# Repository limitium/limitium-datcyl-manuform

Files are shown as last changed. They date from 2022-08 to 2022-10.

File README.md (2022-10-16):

# Limitium' dactyl manuform
Default is great, however I didn't find a way to use it without hand rests. 

This build solves the problem of missing hand rests.

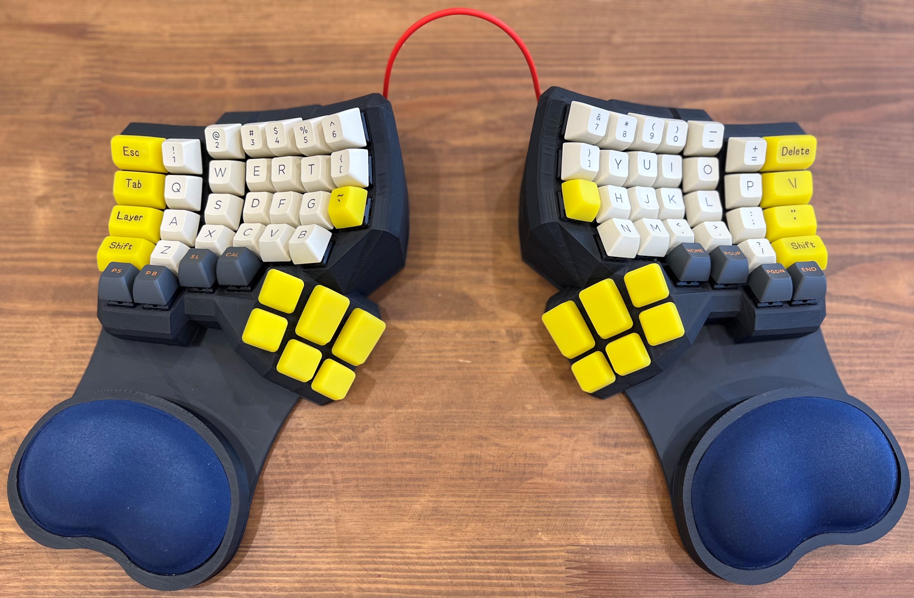
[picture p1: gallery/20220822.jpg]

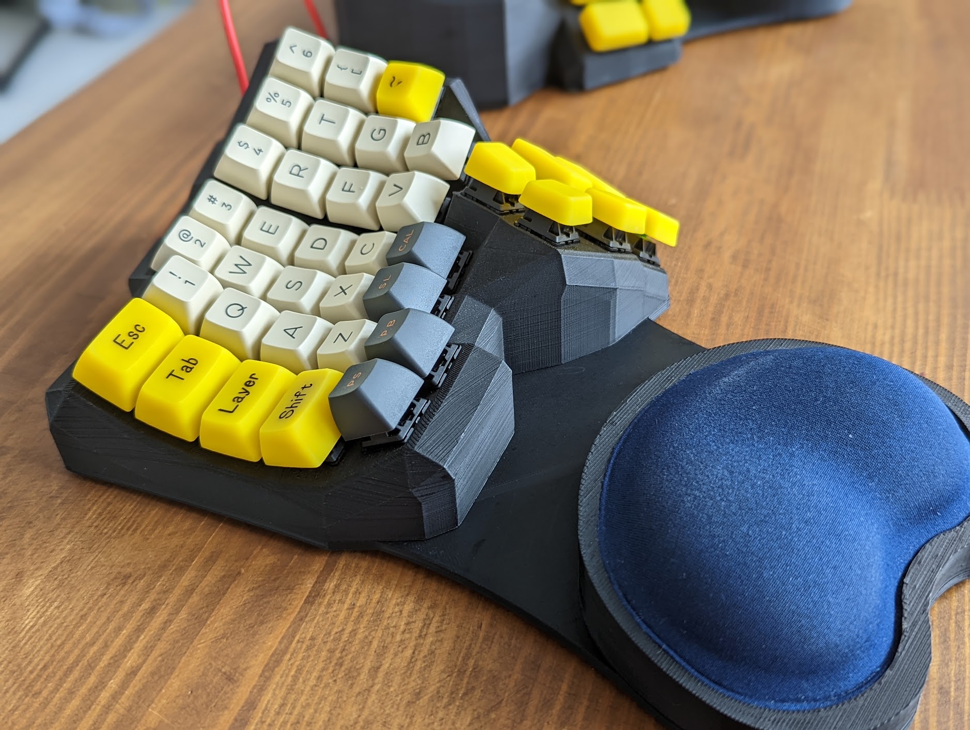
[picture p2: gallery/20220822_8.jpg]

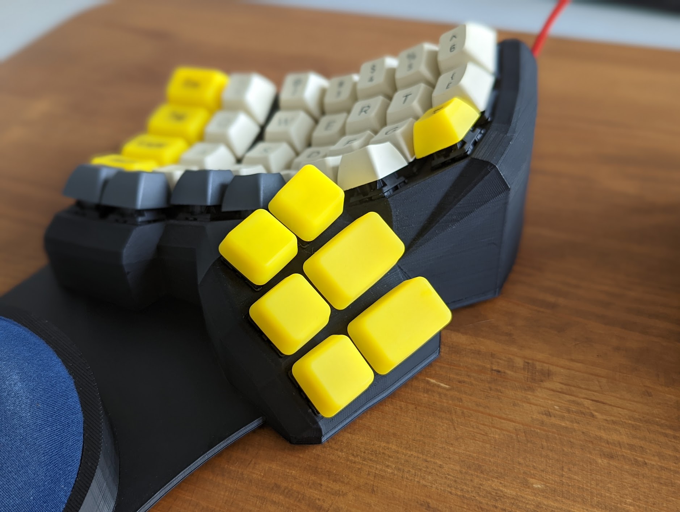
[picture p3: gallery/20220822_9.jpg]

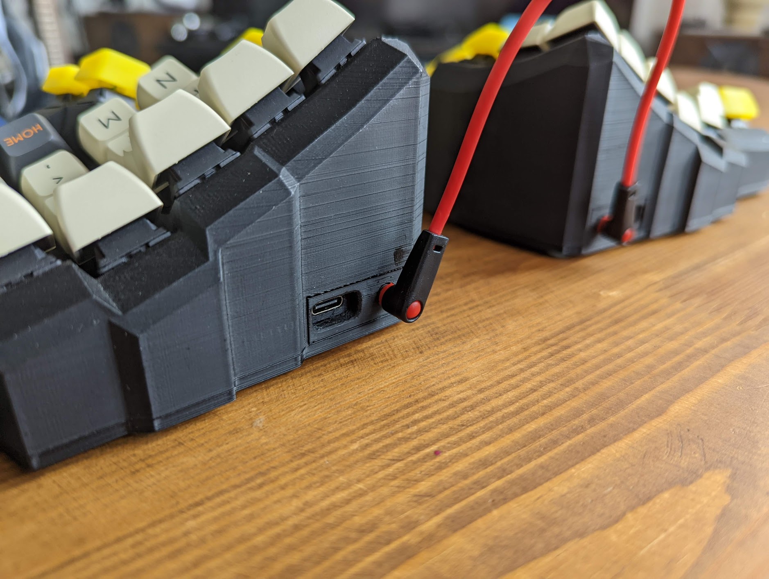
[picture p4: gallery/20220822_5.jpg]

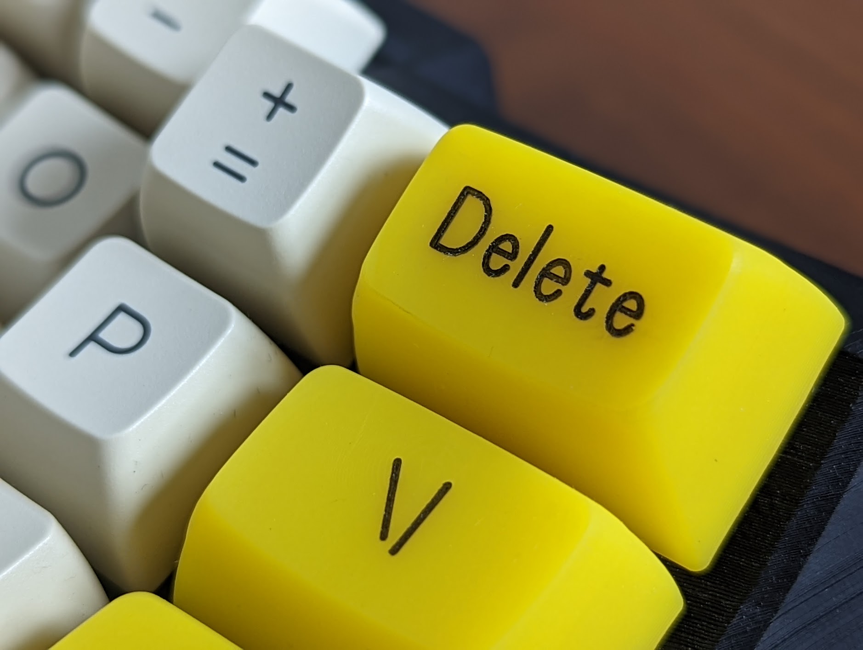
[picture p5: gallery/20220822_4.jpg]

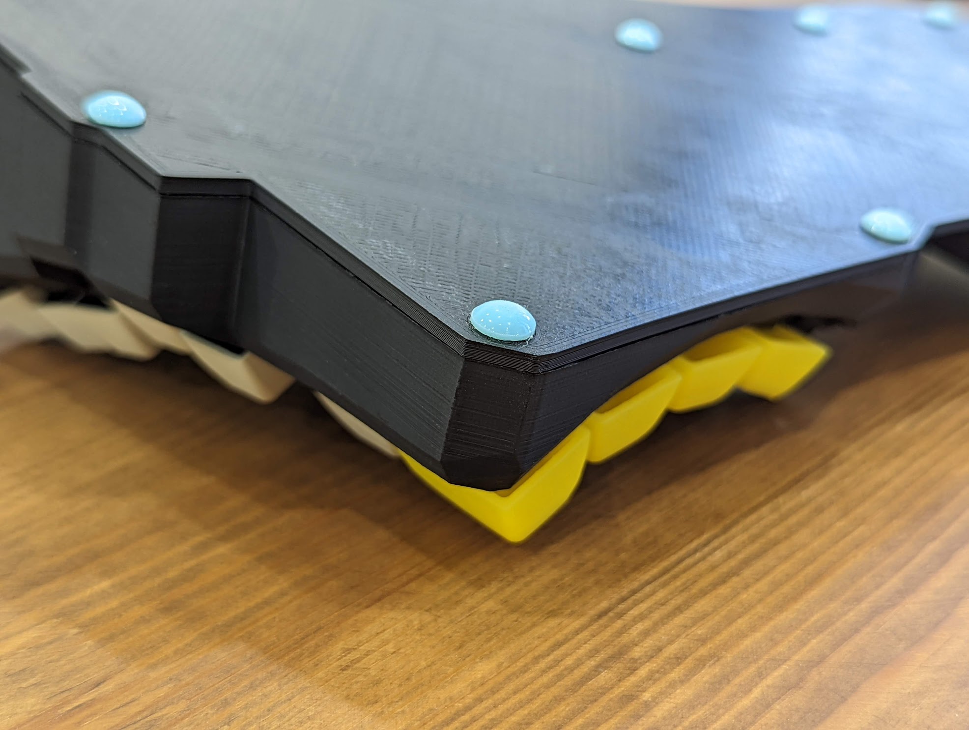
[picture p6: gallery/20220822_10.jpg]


## Table of contents
- [Limitium' dactyl manuform](#limitium-dactyl-manuform)
  - [Table of contents](#table-of-contents)
- [Build](#build)
  - [BOM](#bom)
  - [Body](#body)
    - [Handrest](#handrest)
    - [Promicro holder](#promicro-holder)
  - [Keycaps](#keycaps)
    - [ASA profile](#asa-profile)
      - [Carbon Retro Keycap Set from Akko](#carbon-retro-keycap-set-from-akko)
      - [Custom KeyV2](#custom-keyv2)
  - [Wiring](#wiring)
  - [Firmware](#firmware)

# Build

## BOM
* ANYCUBIC 4Max Pro 2.0 FDM 3D Printer        https://www.aliexpress.com/item/3256801441789044.html 186$
* ANYCUBIC Mono 4k UV Resin Printer           https://www.aliexpress.com/item/3256802616795467.html 181$
* AKKO Carbon Retro keycaps AKKO Carbon Retro https://www.aliexpress.com/item/3256803365319134.html 66$
* 74 cherry mx like switches                  https://www.aliexpress.com/item/3256801888735506.html 48$
* 74 1N4148 diods                             https://www.aliexpress.com/item/2251832635934304.html 1$
* 0.3 Brass copper wire                       https://www.aliexpress.com/item/2251832673616354.html 1.4$
* 2 usb-c promicro controller                 https://www.aliexpress.com/item/3256801435571628.html 15$
* 20 M3 3mm length self tapping insert        https://www.aliexpress.com/item/2251832821826942.html 1.5$
* 20 M3 flat hex screws                       https://www.aliexpress.com/item/2255799867108667.html 2$
* 20 silicone pads                            https://www.aliexpress.com/item/3256802432366448.html 3$
* 2 XH2.54 6p 90degree connector              https://www.aliexpress.com/item/2251832636946873.html 2$
* 2 XH2.54 7p 90degree connector              https://www.aliexpress.com/item/2251832636946873.html 2$
* 2 XH2.54 6p single head cable               https://www.aliexpress.com/item/3256801288158320.html 2$
* 2 XH2.54 7p single head cable               https://www.aliexpress.com/item/3256801288158320.html 2$
* 2 TRRS sockets                              https://www.aliexpress.com/item/2251832834540787.html 1.4$
* TRRS cable                                  https://www.aliexpress.com/item/3256801400545299.html 2.4$
* 2 heart-shaped wrist rest                   https://www.aliexpress.com/item/3256801631342023.html 11$
* eSun 0.5 yellow washable resin              https://www.aliexpress.com/item/3256802101772974.html 19$
* Sunlu black abs                             https://www.aliexpress.com/item/2255801034999072.html 18$

## Body
Different body types and modifications were tried, but ended up with a carbonfet fork of Dactyl manuform with a little thumb cluster tweaking https://github.com/limitium/dactyl-manuform

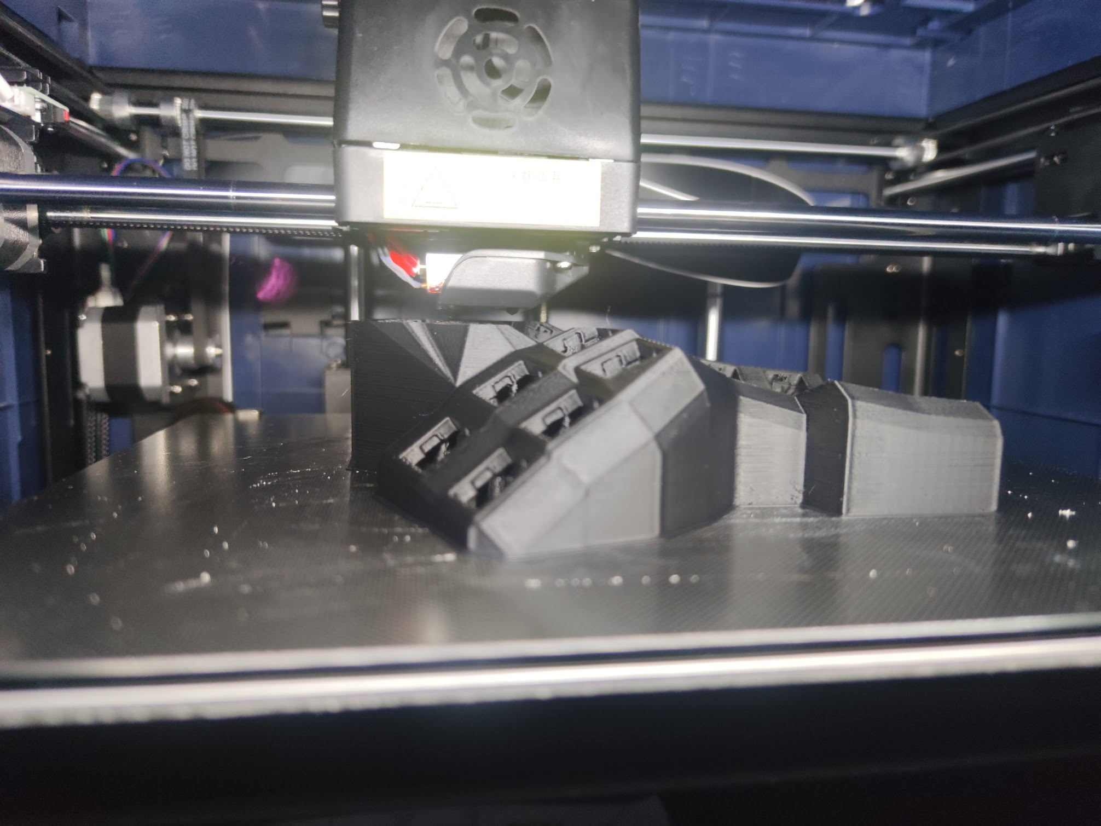
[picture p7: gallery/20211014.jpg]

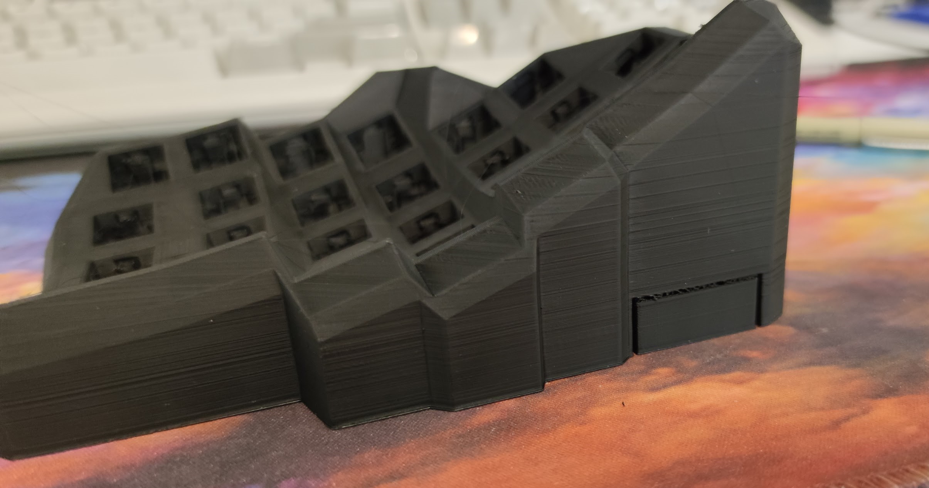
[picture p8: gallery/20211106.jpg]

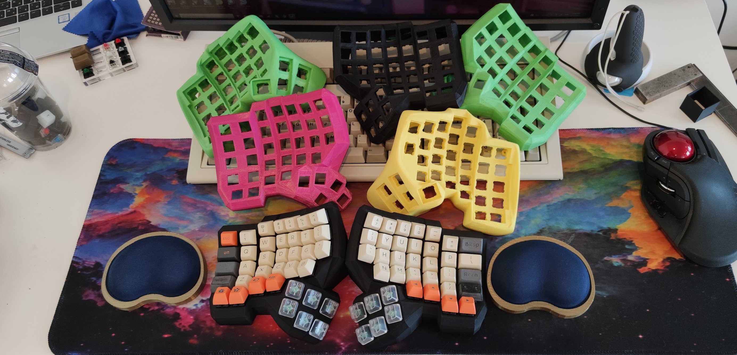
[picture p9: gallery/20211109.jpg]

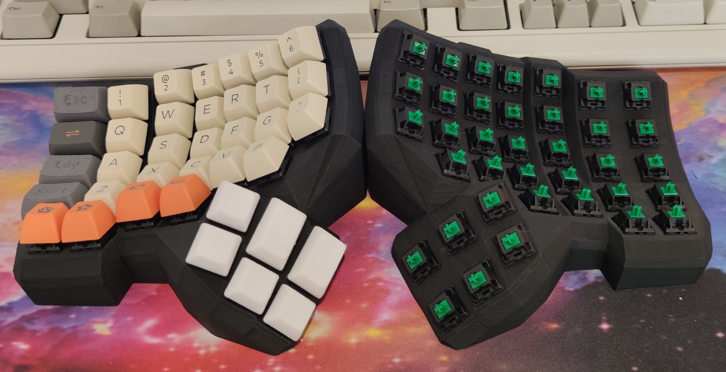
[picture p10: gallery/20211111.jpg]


### Handrest
Integrated plate is made from a dactyl manuform back plate and a hand rest model

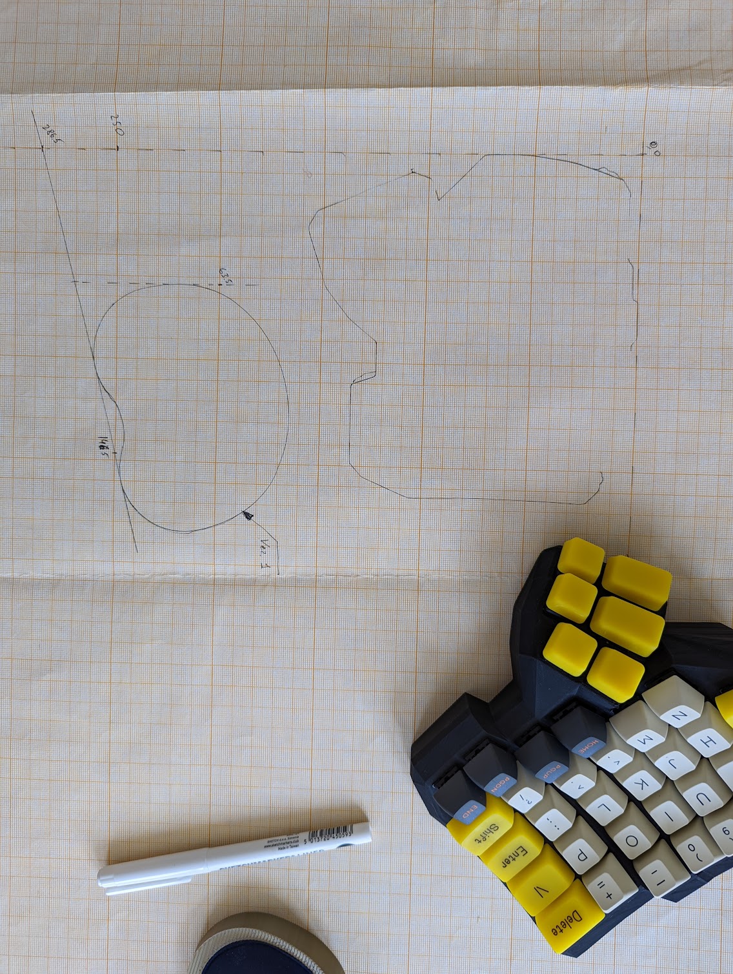
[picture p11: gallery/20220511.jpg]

limitium dactyl manuform
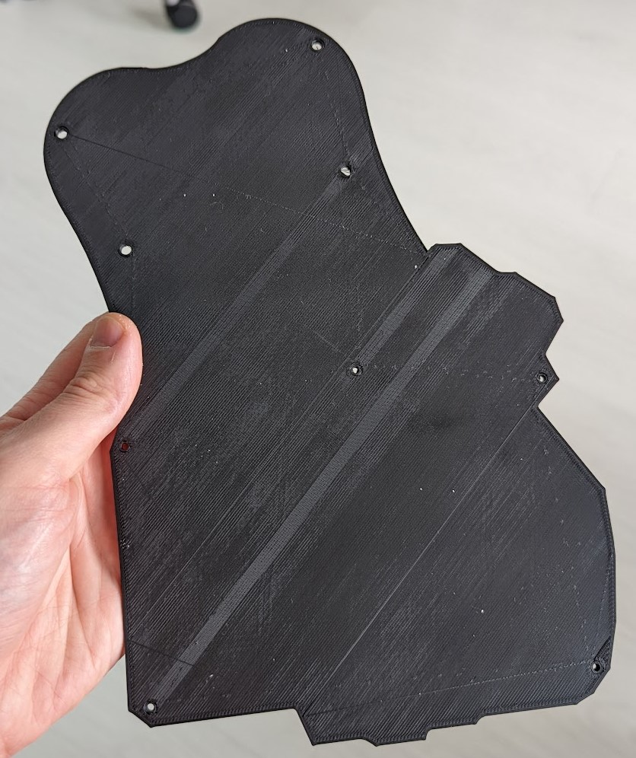
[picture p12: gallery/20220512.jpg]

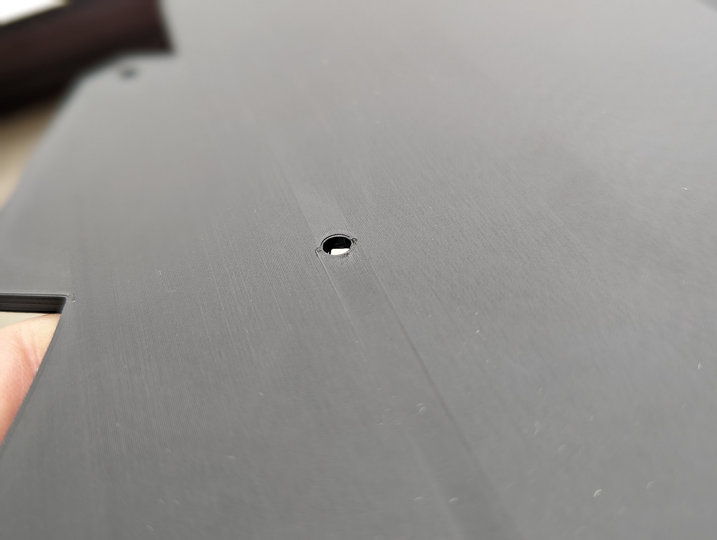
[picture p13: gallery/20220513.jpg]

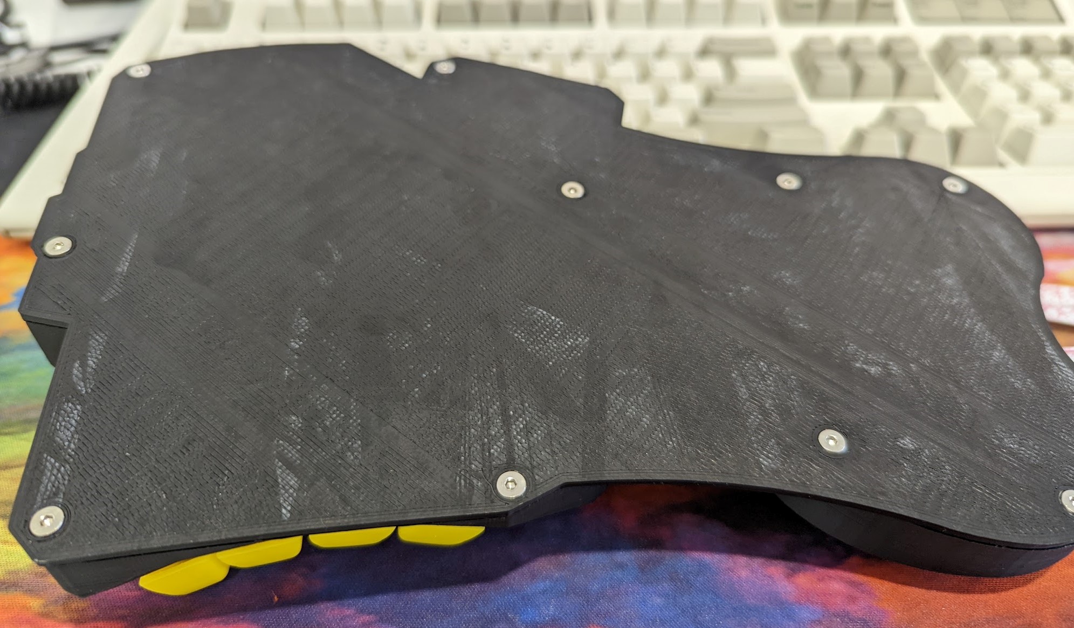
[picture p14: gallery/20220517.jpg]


### Promicro holder

The last type-c Promicro controller is slightly longer, so a new version of the holder is required.

New version is a glue-less click-in holder for TRRS jack and type-c Promicro

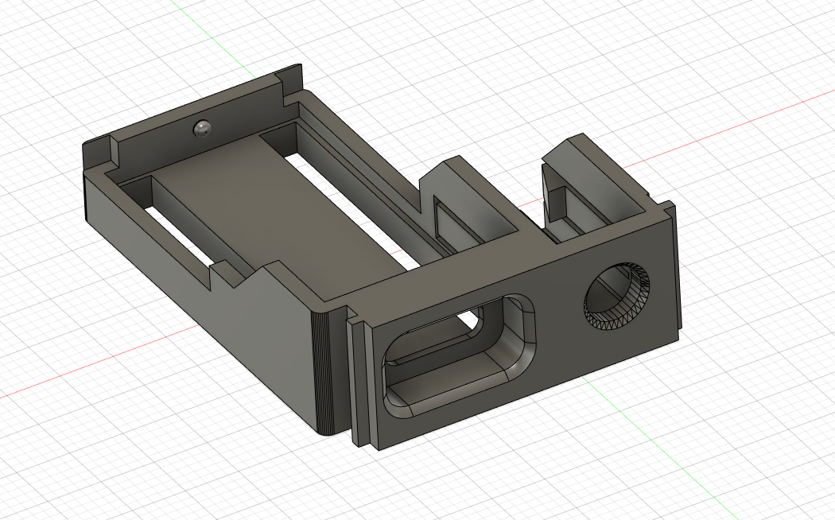
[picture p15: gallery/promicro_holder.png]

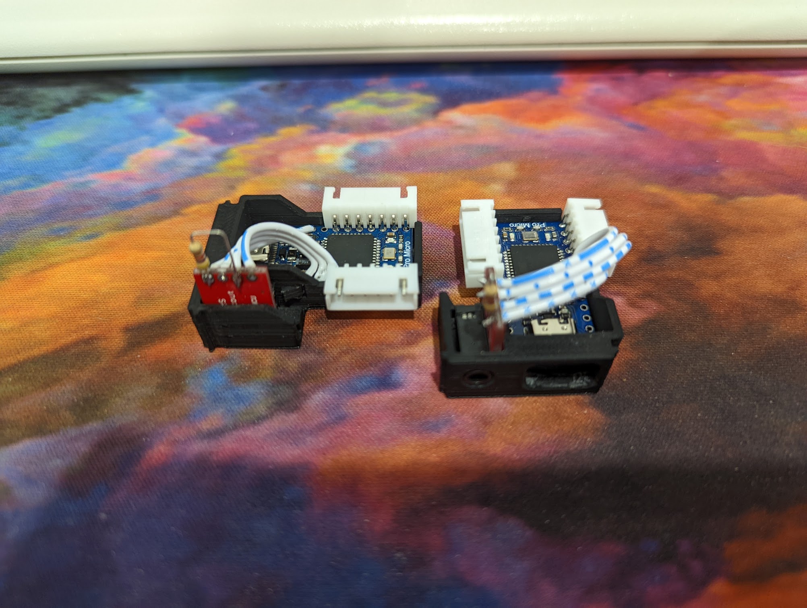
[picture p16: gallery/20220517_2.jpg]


## Keycaps

Dactyl manufrom was designed for a SA like profile for additional curvature. Any profile from the SA family can be taken.

### ASA profile

SA profile is too tall for my taste, so switched to ASA.

#### Carbon Retro Keycap Set from Akko
It makes no sense to buy the whole set if a resin printer is available.

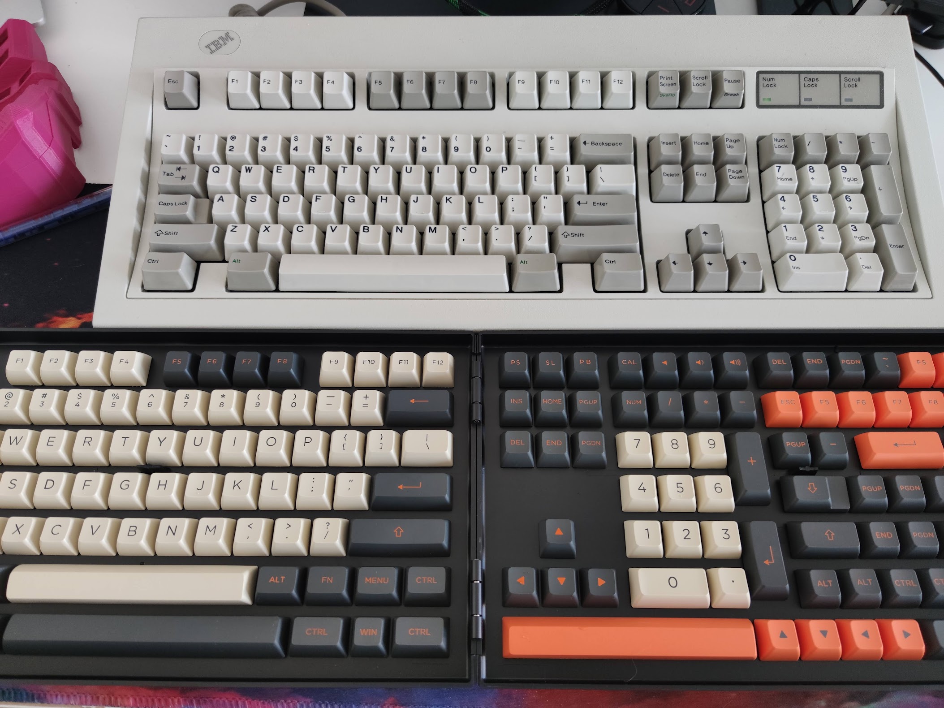
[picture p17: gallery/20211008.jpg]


#### Custom KeyV2 
The missing keycaps are printed on a resin printer and modeled via https://github.com/rsheldiii/KeyV2 project, with https://www.ffonts.net/Gorton-Digital-Regular.font font for chars and https://github.com/dakotafelder/open-gorton font for specials keys.

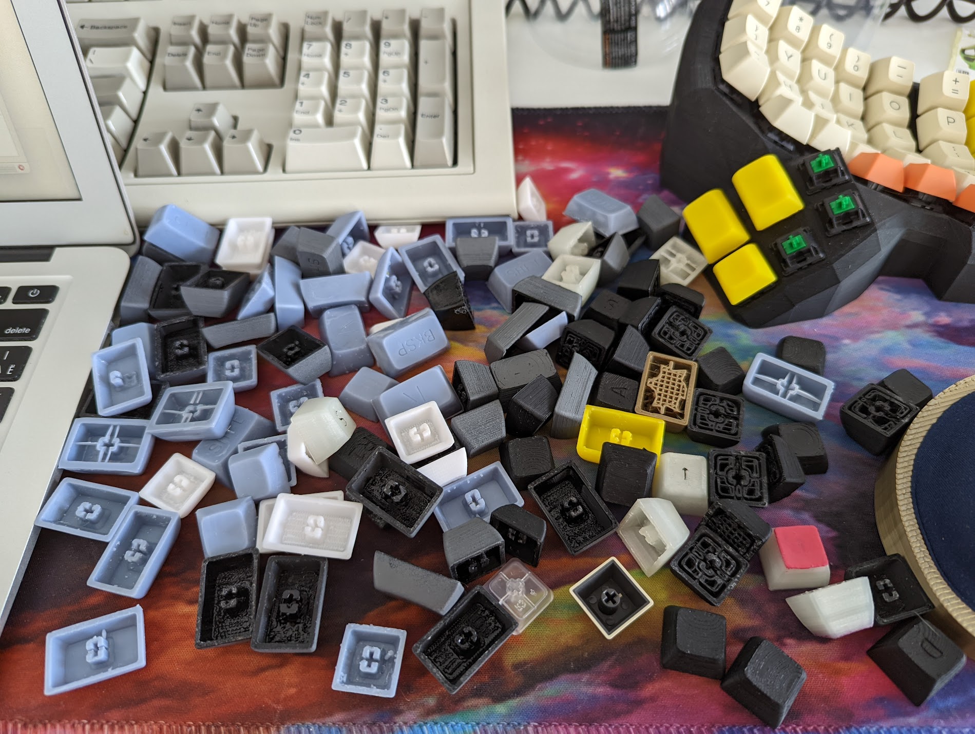
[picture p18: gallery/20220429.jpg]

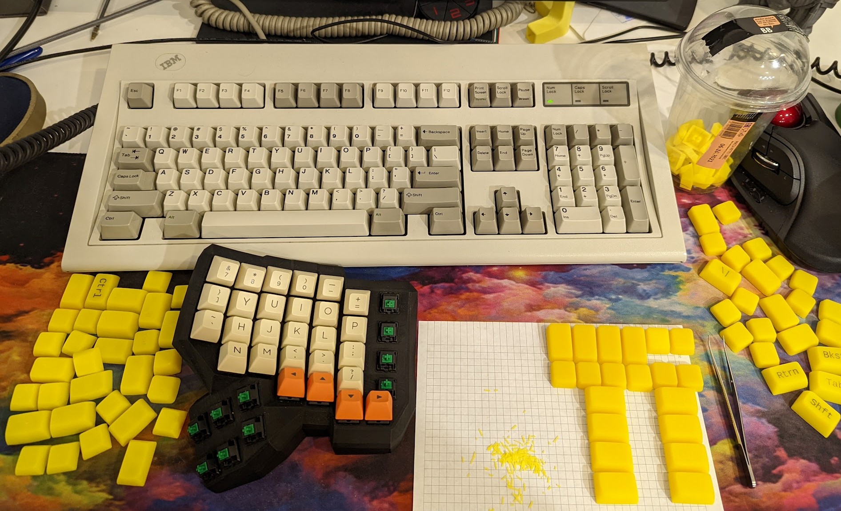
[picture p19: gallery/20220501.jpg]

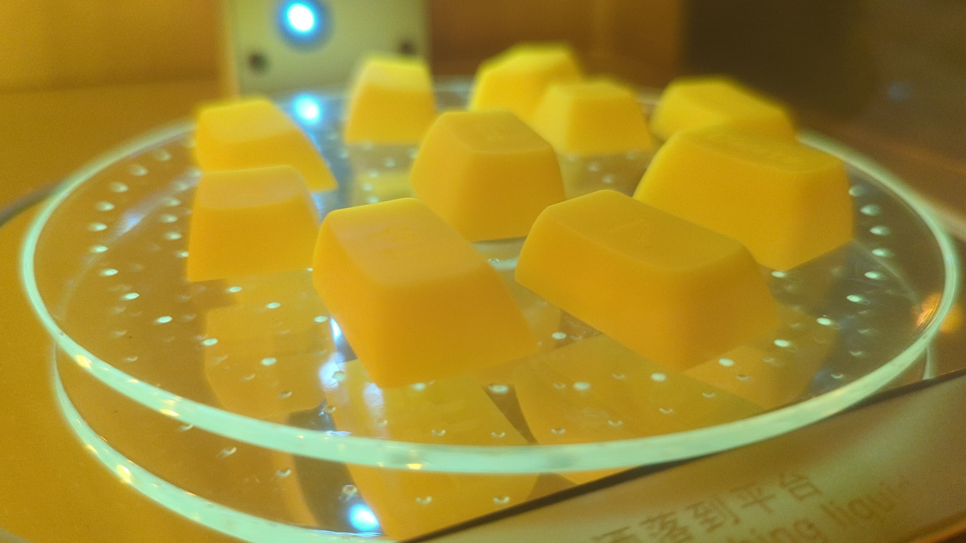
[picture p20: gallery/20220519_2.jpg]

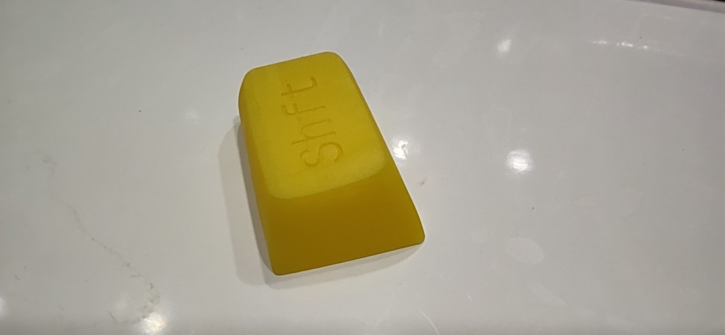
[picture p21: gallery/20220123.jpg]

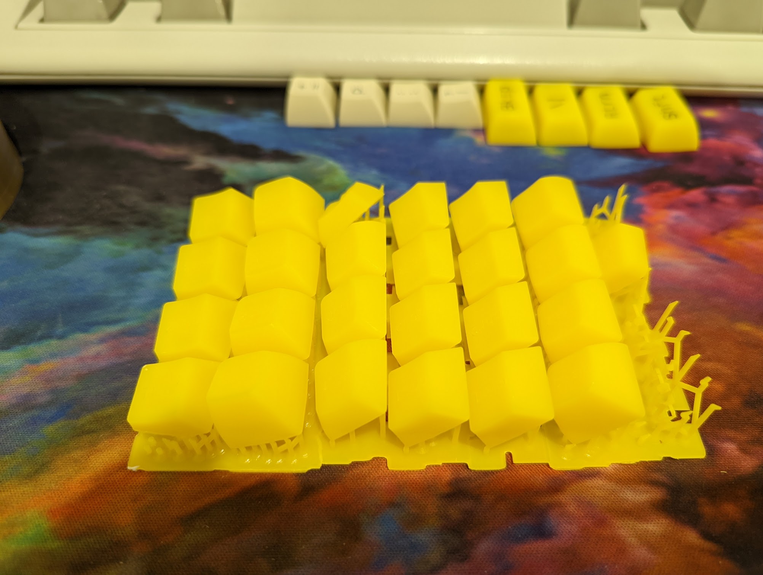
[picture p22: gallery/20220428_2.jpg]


For the thumb cluster g20 low profile was used.
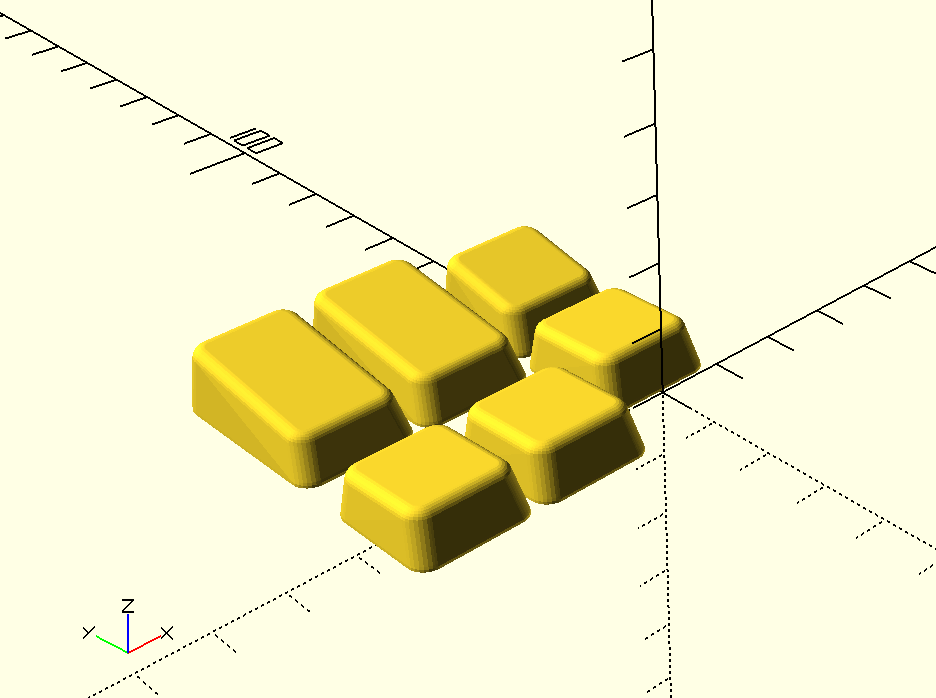
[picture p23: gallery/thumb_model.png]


## Wiring
Default QMK split wiring https://docs.qmk.fm/#/feature_split_keyboard with diods and naked wires. The rows and columns are connected to a Promicro controller with XH2.54 connectors

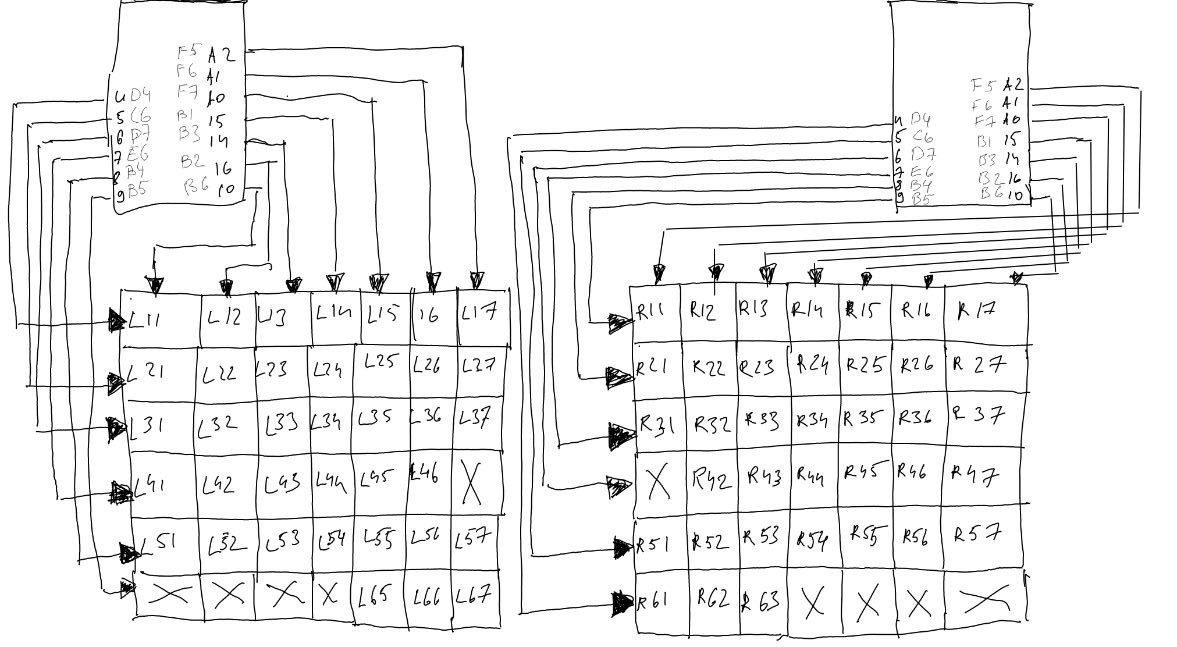
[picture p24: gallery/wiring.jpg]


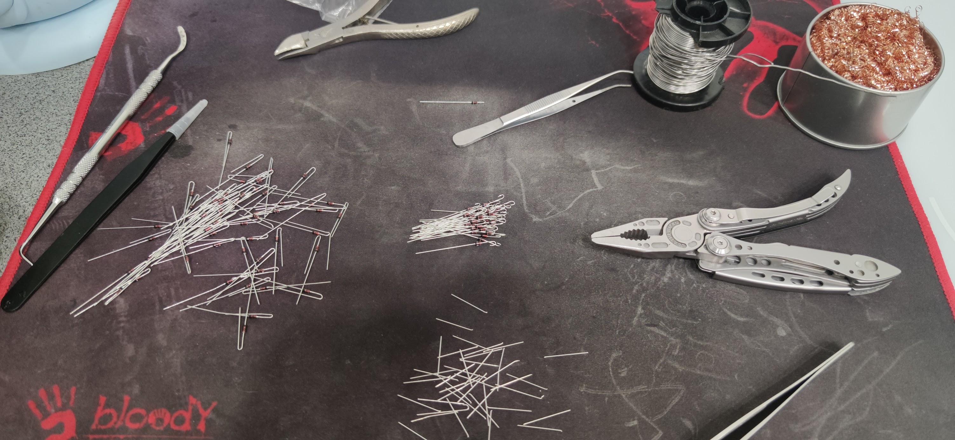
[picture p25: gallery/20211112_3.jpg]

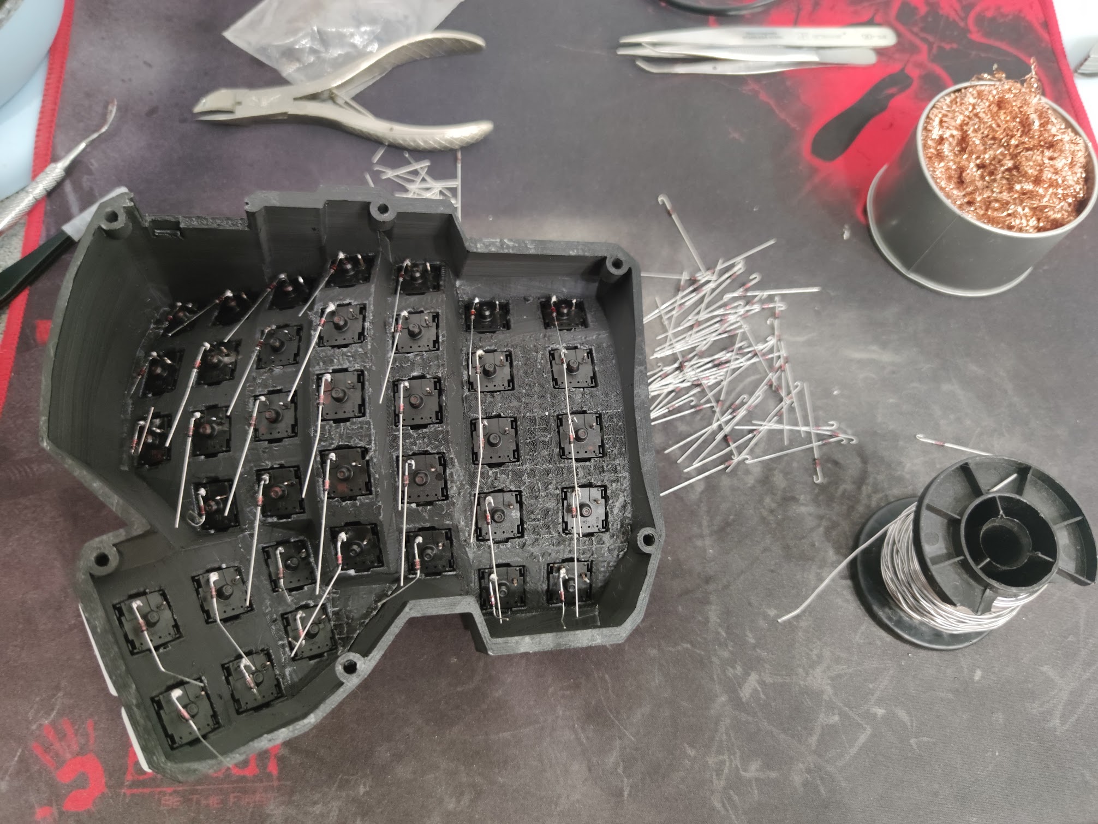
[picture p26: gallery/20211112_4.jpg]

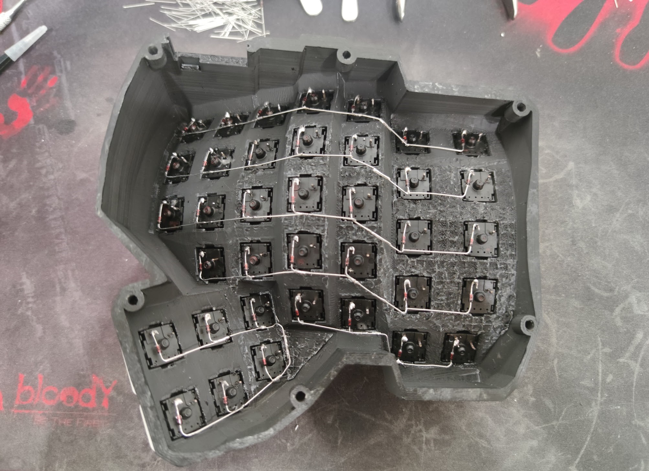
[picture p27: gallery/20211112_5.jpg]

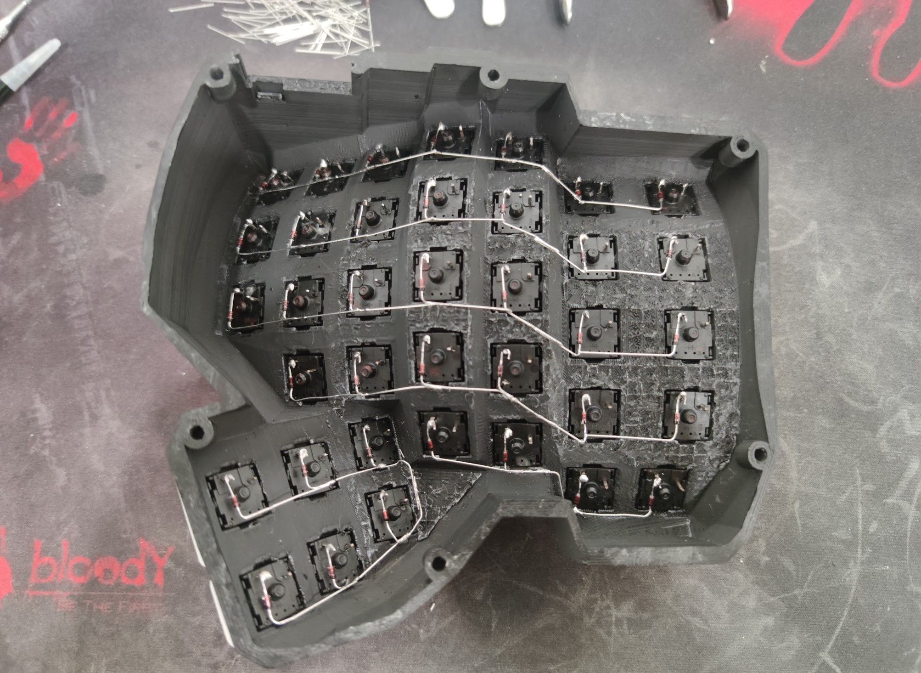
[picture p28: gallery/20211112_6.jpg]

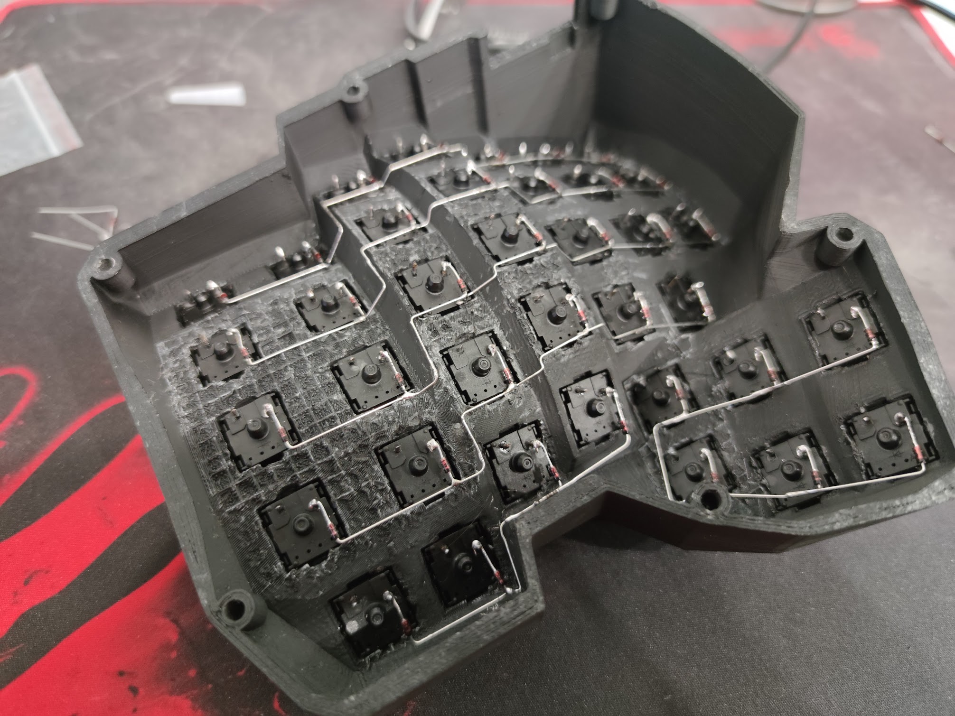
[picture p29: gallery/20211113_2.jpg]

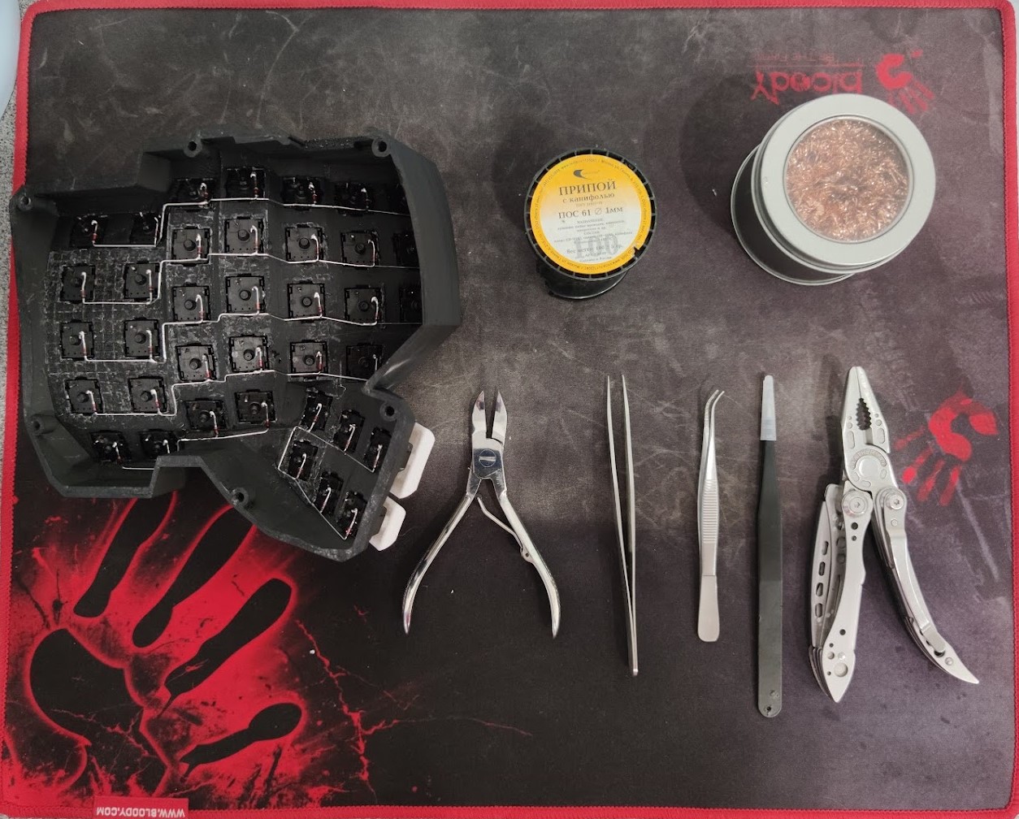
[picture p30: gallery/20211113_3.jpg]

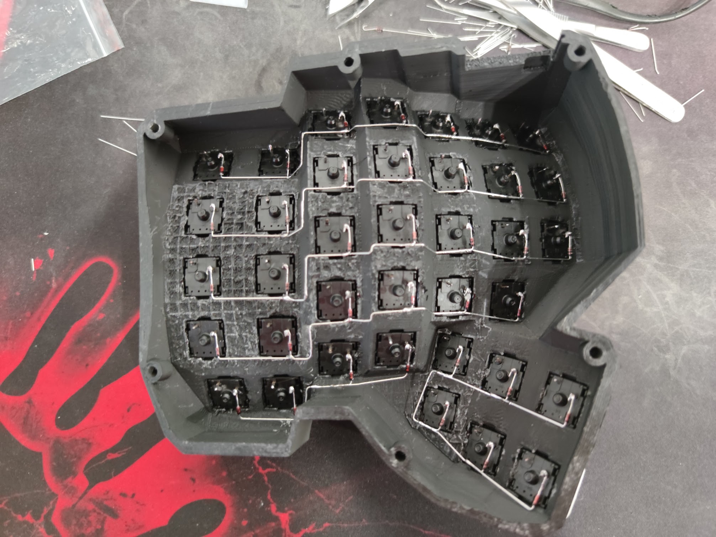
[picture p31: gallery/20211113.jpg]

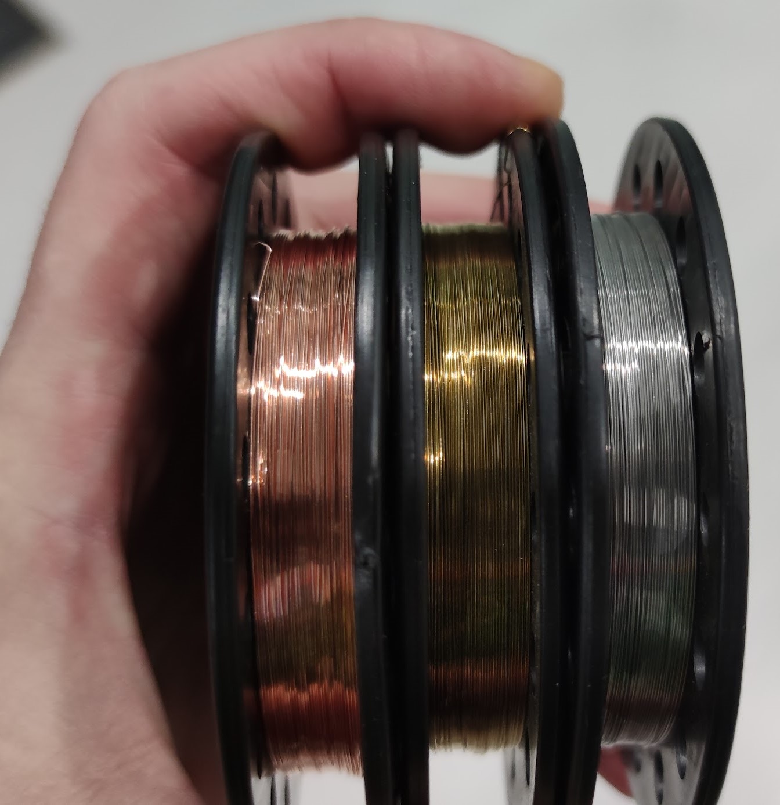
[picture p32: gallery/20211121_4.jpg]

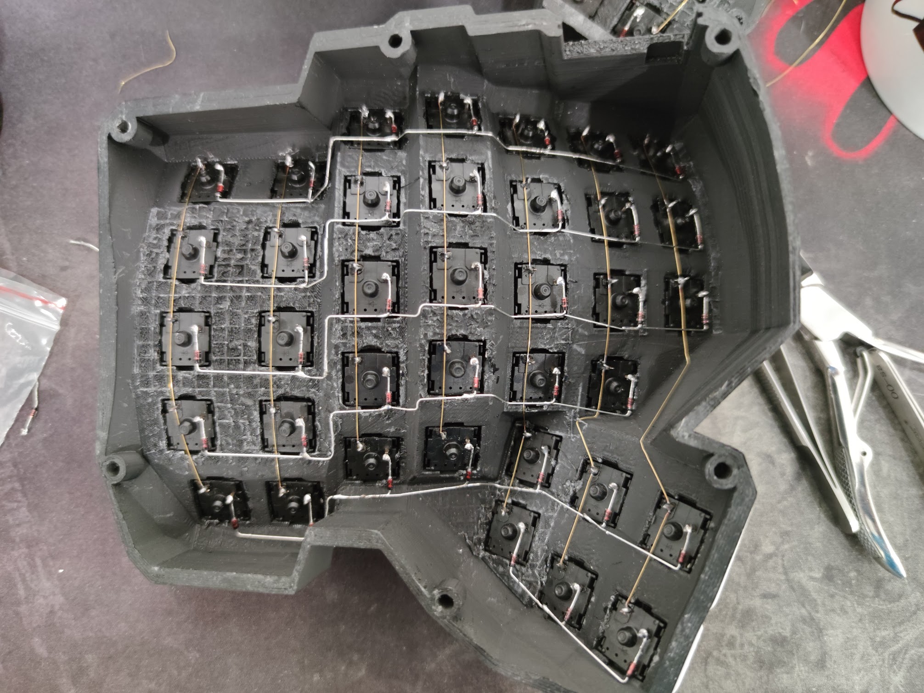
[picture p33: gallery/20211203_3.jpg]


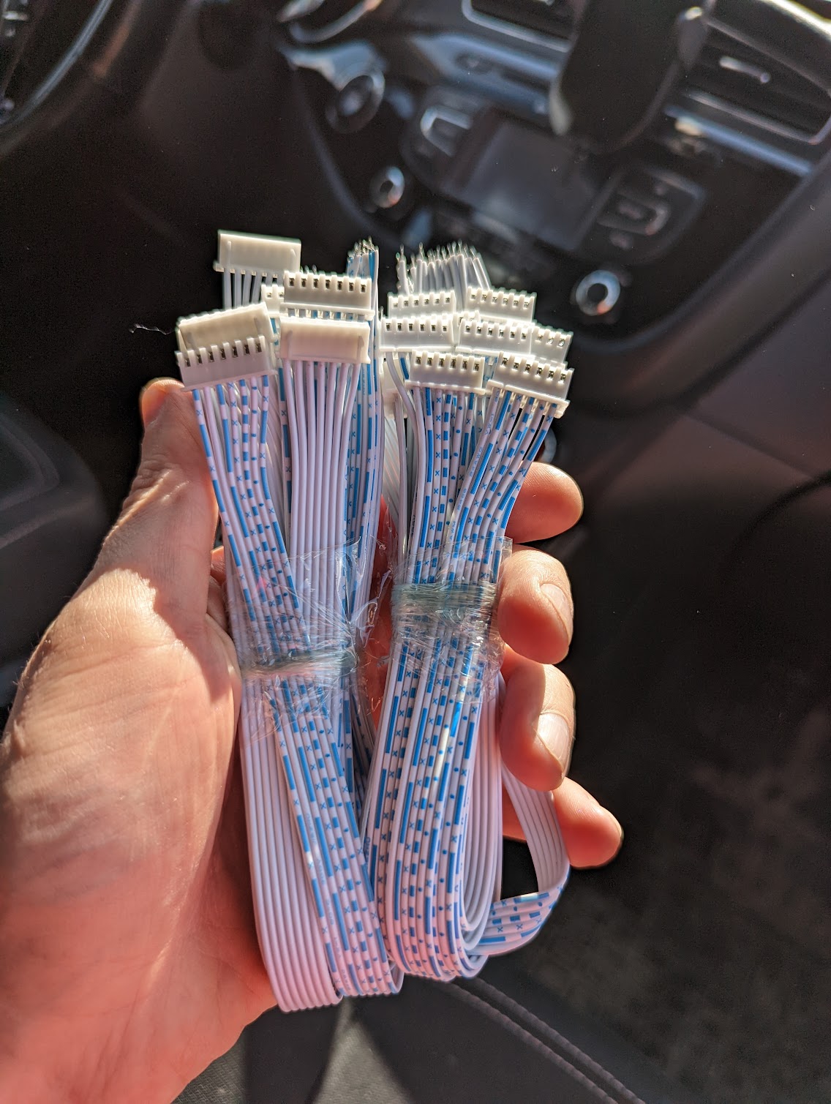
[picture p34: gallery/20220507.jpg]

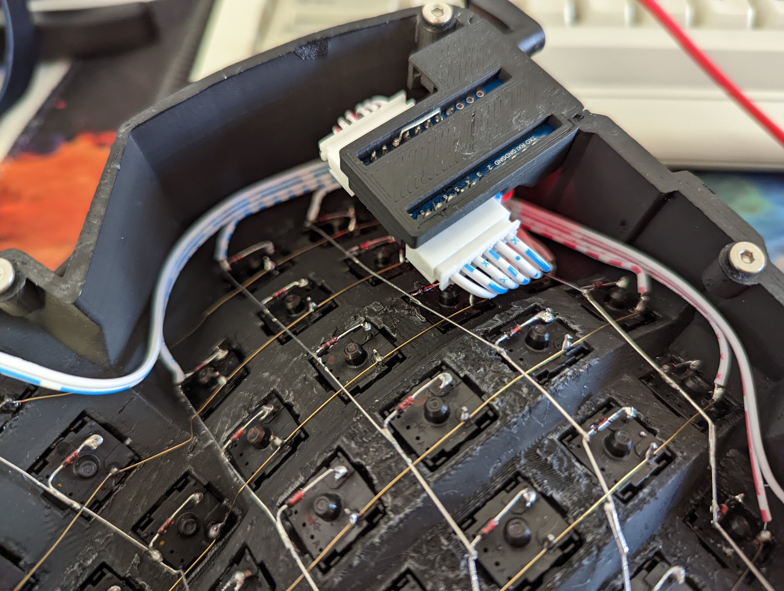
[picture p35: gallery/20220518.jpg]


## Firmware
QMK firmware for split keyboard

with a custom keyboard configuration and layout https://github.com/limitium/qmk_firmware/tree/master/keyboards/handwired/dactyl_lim_5x7

Handedness set by EEPROM

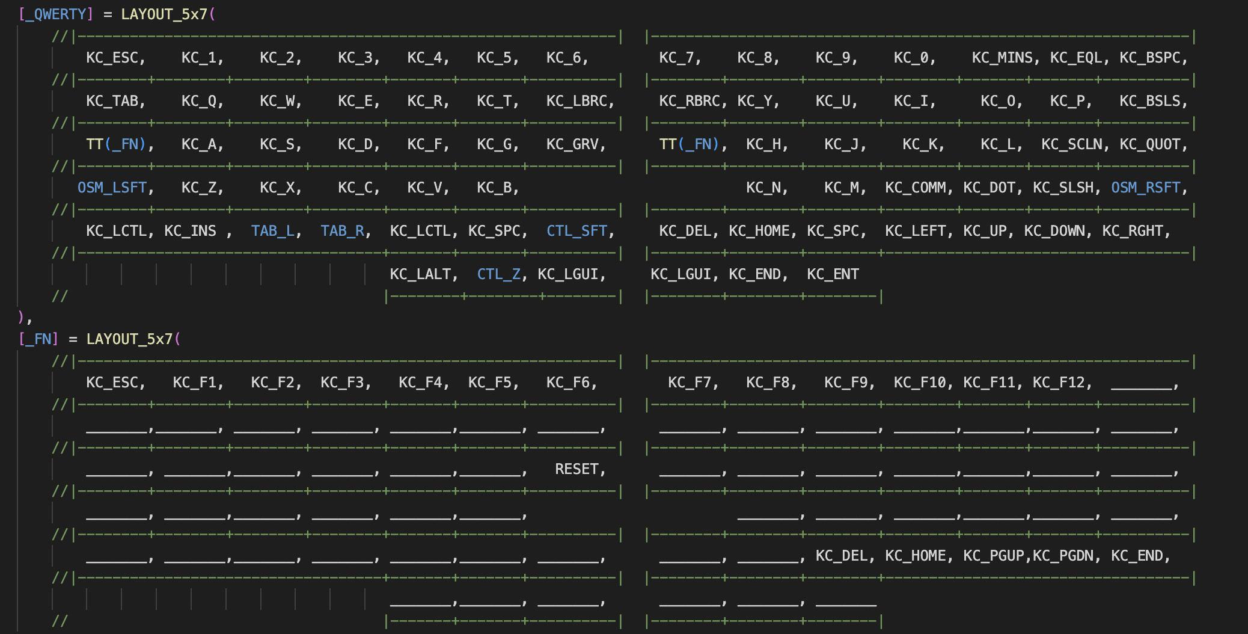
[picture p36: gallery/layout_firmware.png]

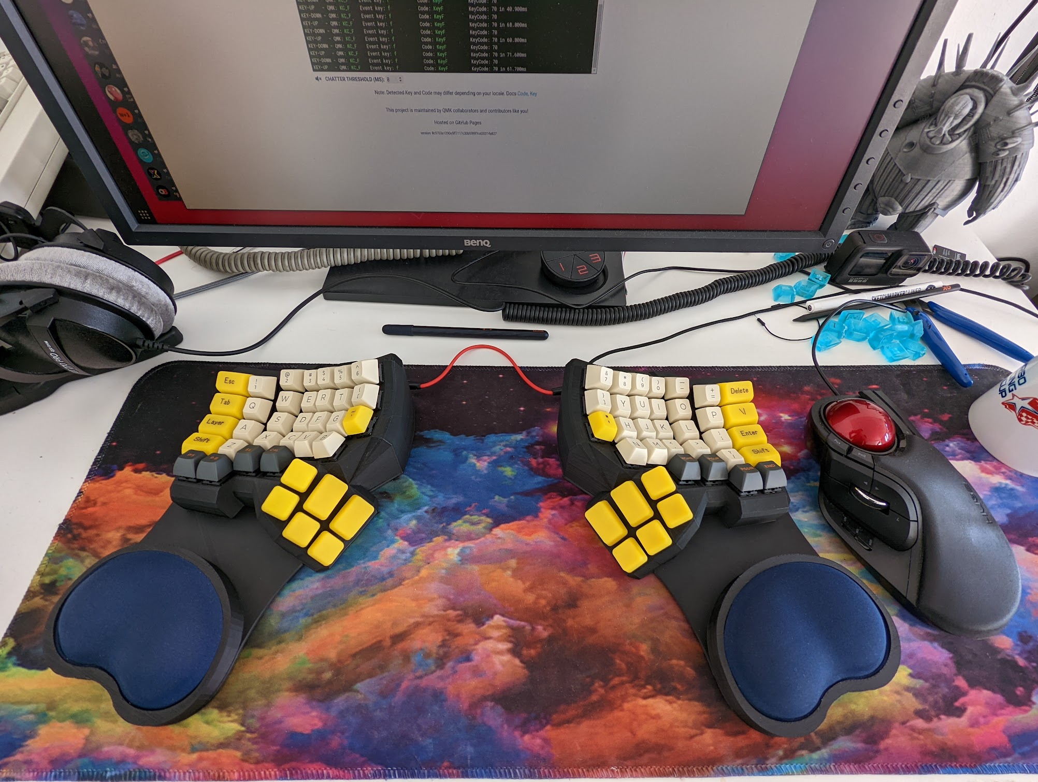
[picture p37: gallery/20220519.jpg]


Layout is really basic one and far from an ideal. It's still under construction.

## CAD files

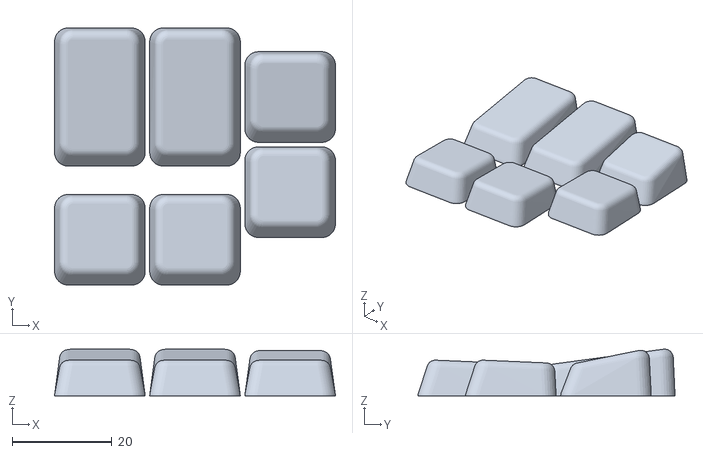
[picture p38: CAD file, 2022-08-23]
stl/thumb.stl
56.3 x 51.5 x 9.34

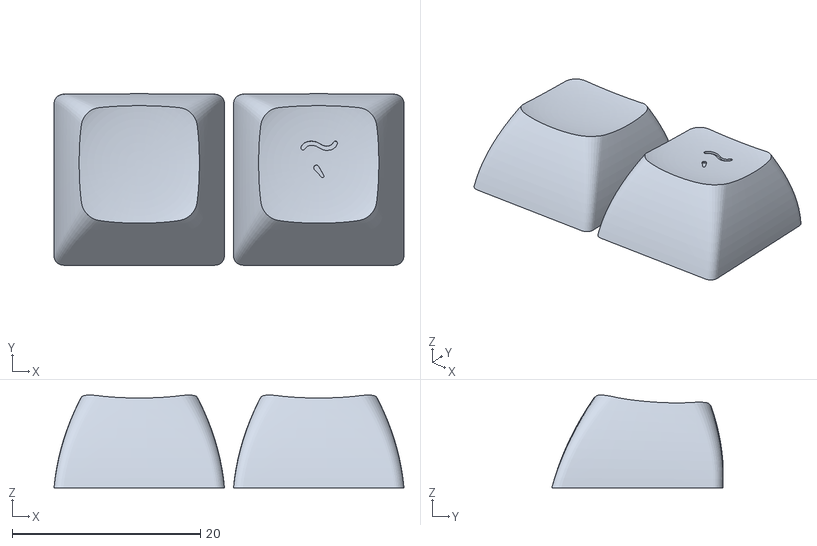
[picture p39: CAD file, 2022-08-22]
stl/3rd-row-extra.stl
37.1 x 18.2 x 9.86

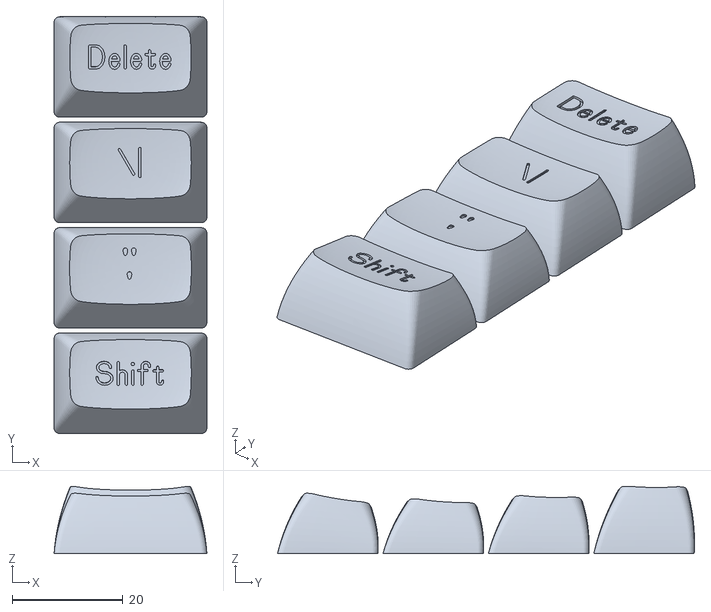
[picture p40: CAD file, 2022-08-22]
stl/right-functional-column.stl
27.6 x 75.4 x 12.2

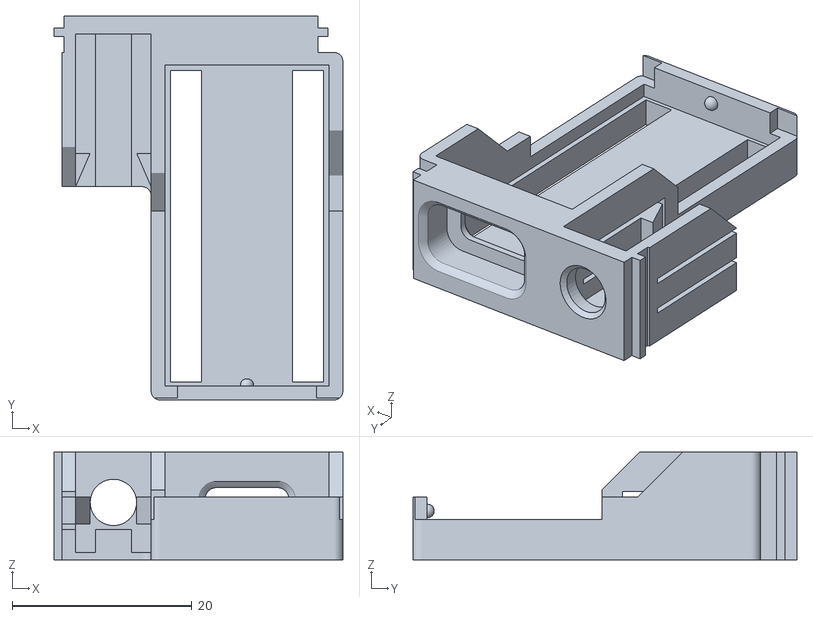
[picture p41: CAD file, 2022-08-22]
stl/right-holder.stl
32.2 x 42.7 x 12.0

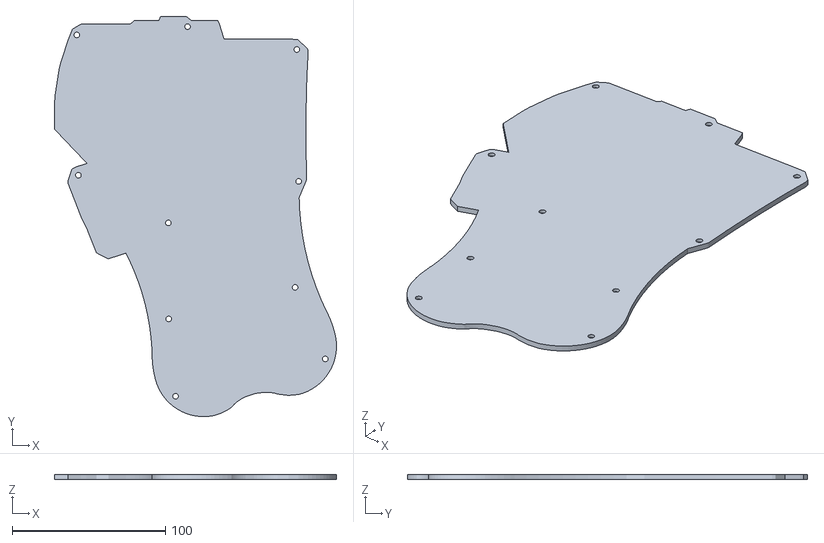
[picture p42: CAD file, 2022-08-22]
stl/right-plate.stl
184.1 x 261.3 x 3.00

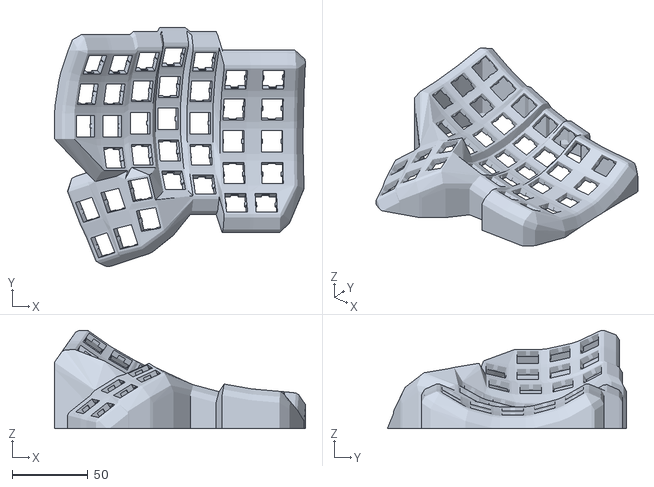
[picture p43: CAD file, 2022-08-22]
stl/right-body.stl
165.6 x 157.9 x 64.8

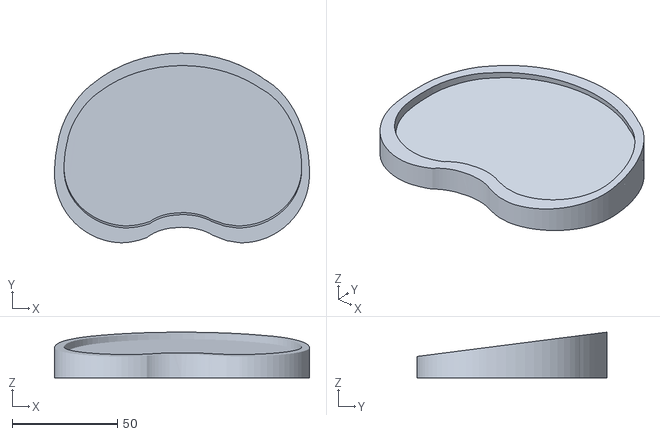
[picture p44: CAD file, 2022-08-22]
stl/right-pad.stl
121.0 x 90.0 x 21.7

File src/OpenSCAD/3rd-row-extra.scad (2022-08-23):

include <./includes.scad>

$font="Open Gorton:style=Regular";
$stem_type="box_cherry";
     
        translate_u(0.5,0) asa_row(row=2) {
            union(){
                    
                  
                
                $extra_long_stem_support = false;
                $stem_slop = 0;
                $stem_inner_slop = 0;
                $stem_type="cherry";
                resin() legend("~",[0,-.3],6) legend("`",[0,1],6) key();
           }            
     
 }
 translate_u(-0.5,0) asa_row(row=2) {
            union(){
            
                $extra_long_stem_support = false;
                $stem_slop = 0;
                $stem_inner_slop = 0;
                $stem_type="cherry";
                resin() //legend("\"",[0,-.3],6) legend("'",[0,1],6) 
                key();
           }            
     
 }


//

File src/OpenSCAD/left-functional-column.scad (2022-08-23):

include <./includes.scad>

legs=["Ctrl","Shift","Layer","Tab","Esc"];

$font="Gorton Digital:style=Regular";

$stem_type="box_cherry";
     
        translate_u(0,1-2.5) asa_row(row=1) {
            union(){
            
                $extra_long_stem_support = true;
    $stem_slop = 0;
    $stem_inner_slop = 0;
    $stem_type="cherry";
                1_5u() legend(legs[1],[0,0],4) key();
           }     
         
     
 }
 
         translate_u(0,2-2.5) asa_row(row=2) {
            union(){
            
                $extra_long_stem_support = true;
    $stem_slop = 0;
    $stem_inner_slop = 0;
    $stem_type="cherry";
                1_5u() legend(legs[2],[0,0],4) key();
           }     
         
     
 }
 
         translate_u(0,3-2.5) asa_row(row=3) {
            union(){
            
                $extra_long_stem_support = true;
    $stem_slop = 0;
    $stem_inner_slop = 0;
    $stem_type="cherry";
                1_5u() legend(legs[3],[0,0],4) key();
           }     
         
     
 }
 
         translate_u(0,4-2.5) asa_row(row=4) {
            union(){
            
                $extra_long_stem_support = true;
    $stem_slop = 0;
    $stem_inner_slop = 0;
    $stem_type="cherry";
                1_5u() legend(legs[4],[0,0],4) key();
           }     
         
     
 }


//

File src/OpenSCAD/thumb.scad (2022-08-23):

include <./includes.scad>

     
translate_u(0,1.5) g20_row(row=1) {
    union(){
    
        $extra_long_stem_support = true;
        $stem_slop = 0;
        $stem_inner_slop = 0;
        $stem_type="cherry";
        1u() legend("",[0,0],4) key();
   }
} 
translate_u(-1,1.5) g20_row(row=1) {
    union(){
    
        $extra_long_stem_support = true;
        $stem_slop = 0;
        $stem_inner_slop = 0;
        $stem_type="cherry";
        1_5uh() legend("",[0,0],4) key();
   }
} 
translate_u(-2,1.5) g20_row(row=1) {
    union(){
    
        $extra_long_stem_support = true;
        $stem_slop = 0;
        $stem_inner_slop = 0;
        $stem_type="cherry";
        1_5uh() legend("",[0,0],4) key();
   }
} 

translate_u(0,0.5) g20_row(row=3) {
    union(){
    
        $extra_long_stem_support = true;
        $stem_slop = 0;
        $stem_inner_slop = 0;
        $stem_type="cherry";
        1u() legend("",[0,0],4) key();
   }  
}

translate_u(-1,0) g20_row(row=3) {
    union(){
    
        $extra_long_stem_support = true;
        $stem_slop = 0;
        $stem_inner_slop = 0;
        $stem_type="cherry";
        1u() legend("",[0,0],4) key();
   }  
}

translate_u(-2,0) g20_row(row=3) {
    union(){
    
        $extra_long_stem_support = true;
        $stem_slop = 0;
        $stem_inner_slop = 0;
        $stem_type="cherry";
        1u() legend("",[0,0],4) key();
   }  
}
      

//

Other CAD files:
stl/left-functional-column.stl
src/OpenSCAD/right-functional-column.scad
src/fusion360/promicro-holder.f3d
src/fusion360/right-pad.f3d
src/fusion360/right-plate.f3d

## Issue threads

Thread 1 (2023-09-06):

Source model file for body is missing

RZarifov, 2023-09-06:
Hello. It is possible to work with just stl, but can you also add the source of the body?

limitium, 2023-09-25:
I've added closure sources of the body

Closed 2023-10-25.

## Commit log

2022-08-22 src, models, photos
    [3rd-row-extra.stl, left-functional-column.stl, promicro-holder.f3d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]
2022-08-23 Add keycup src, BOM
    [3rd-row-extra.scad, left-functional-column.scad, right-functional-column.scad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]
2023-09-25 Add closure sources + fusion pad
    [right-pad.f3d]
